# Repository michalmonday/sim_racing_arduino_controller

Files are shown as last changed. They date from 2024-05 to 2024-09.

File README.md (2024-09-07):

# sim_racing_arduino_controller

This sketch programs Arduino Pro Micro microcontroller to read Logitech pedals, Logitech shifter, and a handbrake as analog input pins. After programming, the microcontroller acts as a controller for sim racing games on PC (it works in all modern games like Assetto Corsa, ACC, iRacing, Forza Horizon 5, BeamNG, F1 23).

A nice feature of this setup is that a single USB connector provides the following inputs to a PC:
* pedals
* shifter
* handbrake
* potentially any other buttons (to add large number of buttons we could use a shift register)

You can see that on images, RS232 connectors have more wires than in the schematics, these are unused and can be ignored (they were connected during testing).

The latency of devices is around 35-40ms as measured during this test:  
https://www.youtube.com/watch?v=JN2piJnbTjY  
  
The sketch is using the ArduinoJoystickLibrary (tested with version 2.1.1):   
https://github.com/MHeironimus/ArduinoJoystickLibrary  

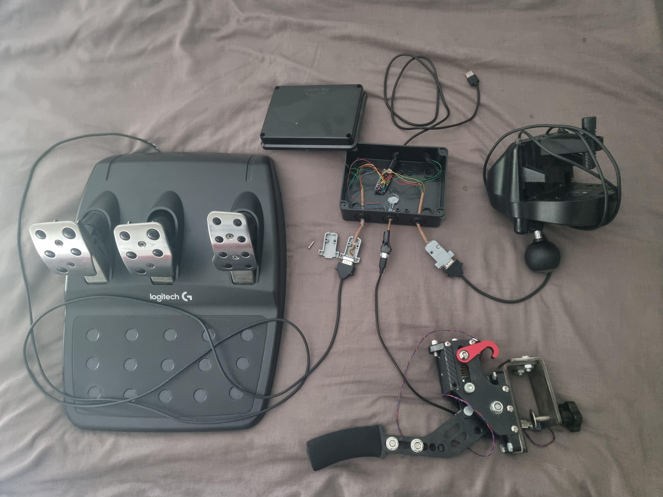
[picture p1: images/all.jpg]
ERROR: IMAGE NOT SHOWN

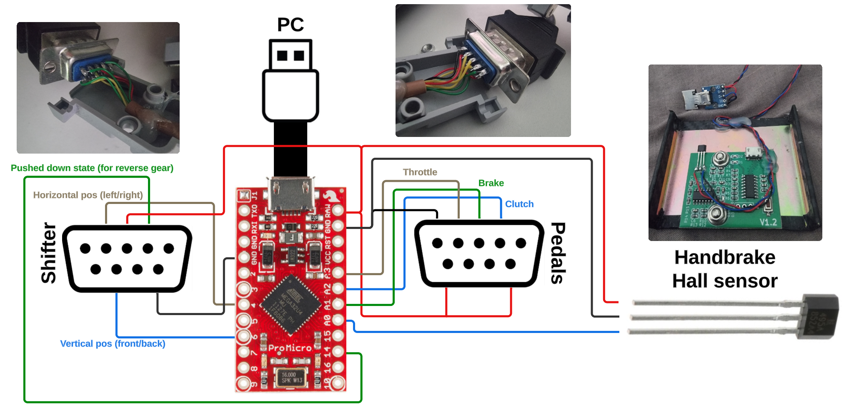
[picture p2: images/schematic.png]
ERROR: IMAGE NOT SHOWN


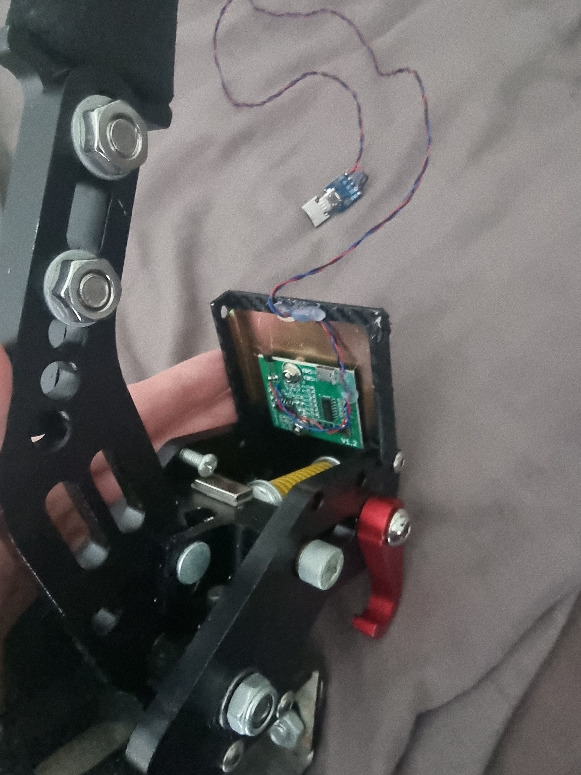
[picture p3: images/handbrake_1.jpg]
ERROR: IMAGE NOT SHOWN


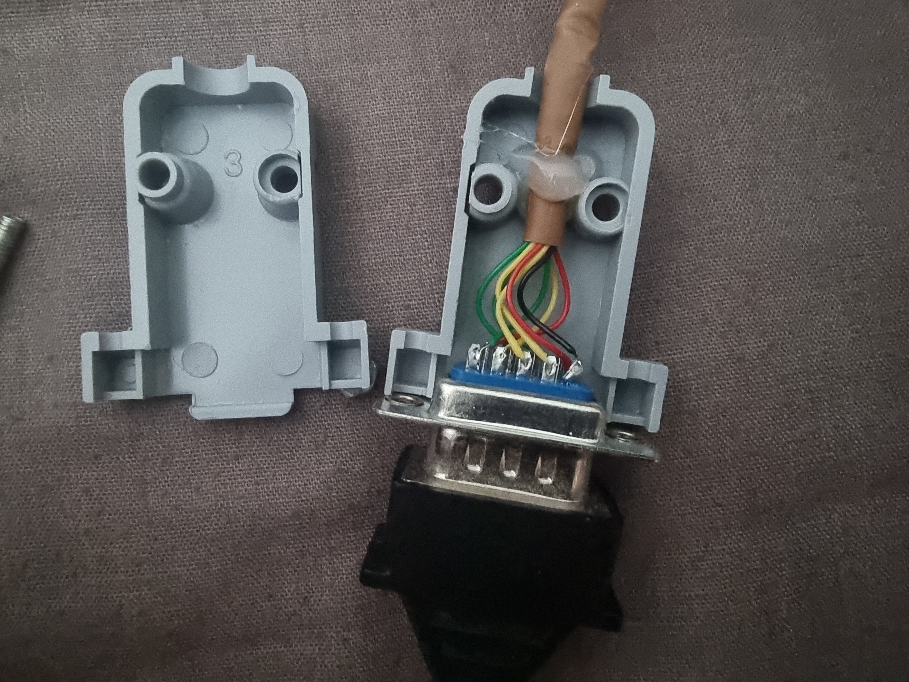
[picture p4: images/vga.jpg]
ERROR: IMAGE NOT SHOWN

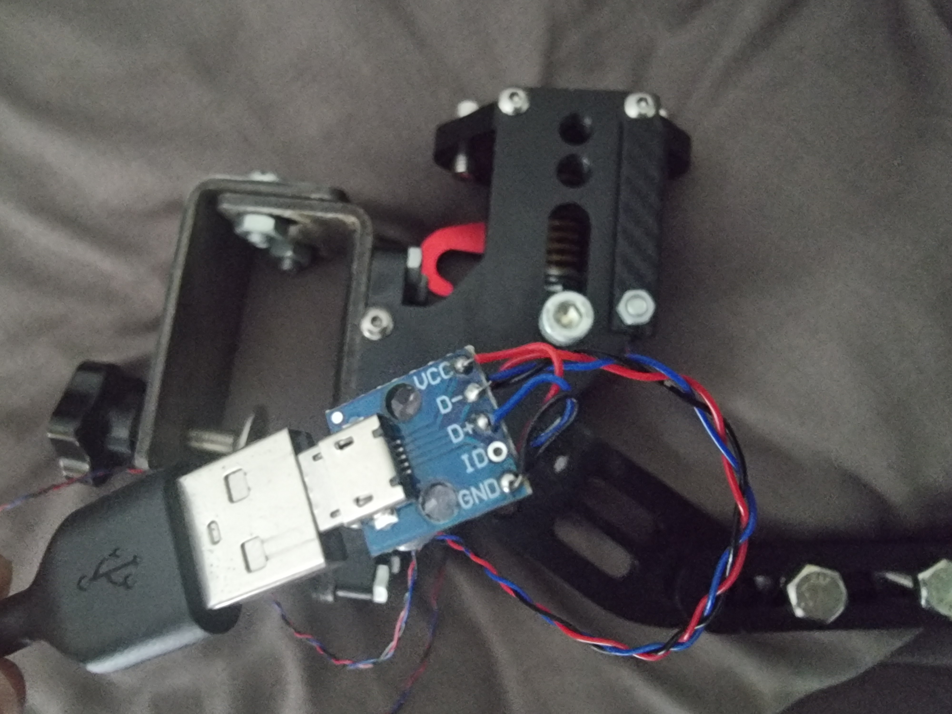
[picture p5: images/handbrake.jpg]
ERROR: IMAGE NOT SHOWN

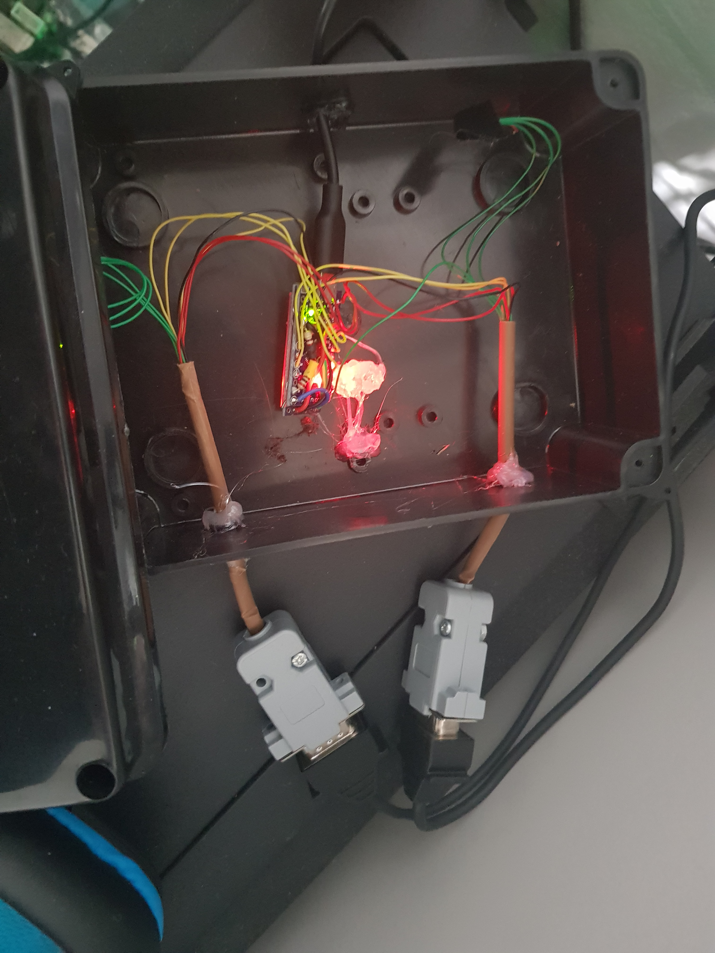
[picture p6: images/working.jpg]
ERROR: IMAGE NOT SHOWN


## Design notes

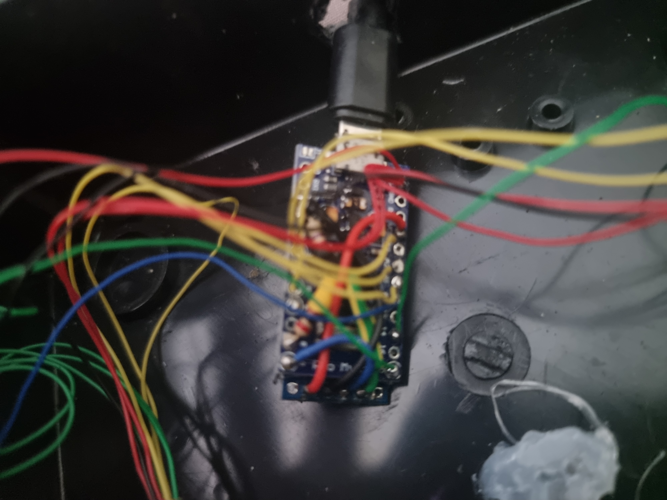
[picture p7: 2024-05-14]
images/close.jpg

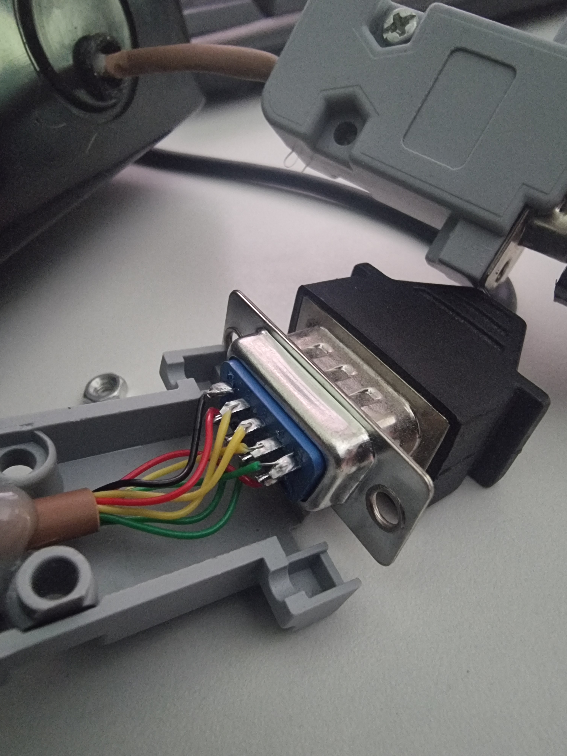
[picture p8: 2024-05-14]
images/rs232.jpg

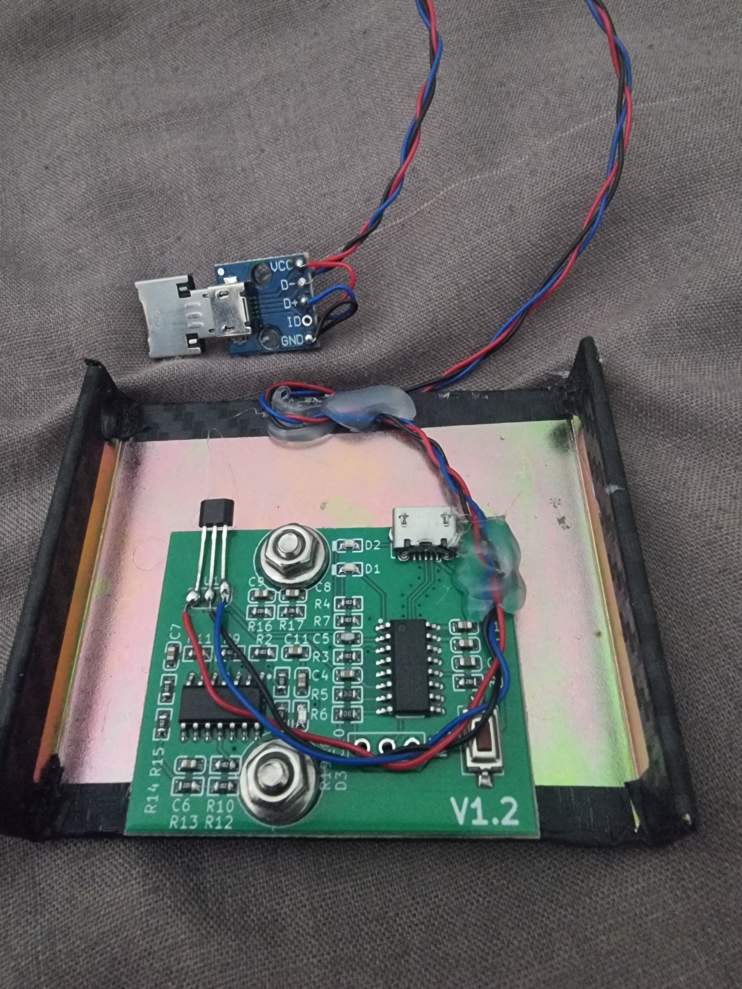
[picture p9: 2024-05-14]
images/handbrake_0.jpg

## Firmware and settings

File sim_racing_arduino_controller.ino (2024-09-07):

// This sketch programs Arduino Pro Micro microcontroller to read Logitech pedals,
// Logitech shifter, and a handbrake as analog input pins. After programming, the microcontroller  
// and acts as a controller for sim racing games on PC (works in all modern games like Assetto Corsa, 
// ACC, iRacing, Forza Horizon 5, BeamNG, F1 23).

// A nice feature of this setup is that a single USB connector provides the following inputs to a PC:
// - pedals
// - shifter
// - handbrake

// Another nice feature is that it could be easily extended with any Arduino sensors/buttons for custom controls.

#include <Joystick.h>



#include "Joystick.h"

#define PIN_SHIFTER_X A6
#define PIN_SHIFTER_Y A7
#define PIN_SHIFTER_REVERSE 14

#define PIN_PEDALS_CLUTCH A2
#define PIN_PEDALS_BRAKE A1
#define PIN_PEDALS_THROTTLE A3

#define PIN_HANDBRAKE A0
#define PIN_ANALOG_INPUT_UNUSED A10

#define BUTTON_COUNT 8


// MIN and MAX values constrain and scale analog read inputs of pedals. 
// (analog inputs should read values between 0 and 1023 but in reality that's not the case)
//
// The purpose of MIN value is to prevent detecting pedal press when it's physically released.
// When pedals are released the input values should be 0, but in reality are something like 50-90 (depending on pedal).
// Setting MIN values process is as follows:
// - open serial monitor
// - see analog read value of a pedal while it's fully released (press and release the pedal few times)
// - set MIN to the highest observed value (plus some added value for safety, if the highest observed value was 50, then MIN value should be 60-90, no less than 50 in any case)
// Setting MIN value too low will brake automatically without pressing the pedal.
// Setting MIN value too high will ignore pedal being pressed until it reaches certain point.

// Similarily, the purpose of MAX is to allow full range of input even if pressing a pedal does not result in 1023 value being registered.
// If we press the pedal fully, and the analog read returns less than 1023 (which is typically the case), the MAX value
// will scale the highest registered value (e.g. 990) to 1023.
// Setting MAX values process is as follows:
// - open serial monitor
// - see analog read value of a pedal while it's fully pressed
// - set MAX to the lowest observed value (minus some for safety, if the highest observed value was 990, then MAX value should be 940-970, no more than 990 in any case)
// Setting too high MAX value will prevent us from accellerating with 100% power. 
// Ssetting too low MAX value will set acceleration to 100% too early (e.g. when the pedal is pressed far from its full range).
#define CLUTCH_MIN 120
#define CLUTCH_MAX 940

#define BRAKE_MIN 80
#define BRAKE_MAX 880

#define THROTTLE_MIN 110
#define THROTTLE_MAX 950

#define HANDBRAKE_MIN 560
#define HANDBRAKE_MAX 730


Joystick_ pedals(
  0x03,                       // Default, don't change
  JOYSTICK_TYPE_MULTI_AXIS,   // Type
  BUTTON_COUNT,               // Button Count
  0,                          // HatSwitch Count
  false,                      // includeXAxis
  false,                      // includeYAxis
  false,                      // includeZAxis
  false,                      // includeRxAxis
  false,                      // includeRyxis
  false,                      // includeRzxis
  false,                       // includeRudder
  true,                       // includeThrottle
  true,                       // includeAccelerator
  true,                       // includeBrake
  true                      // includeSteering
  
);

/*
//Joystick_(0x03, JOYSTICK_TYPE_GAMEPAD, 4, 2, true, true, false, false, false, false, false, false, false, false, false),
Joystick_ gamepad(
  0x04,                       // Default, don't change
  JOYSTICK_TYPE_GAMEPAD,      // Type
  0,                          // Button Count
  2,                          // HatSwitch Count
  false,                       // includeXAxis
  false,                       // includeYAxis
  false,                       // includeZAxis
  true,                      // includeRxAxis
  true,                      // includeRyxis
  false,                      // includeRzxis
  false,                      // includeRudder
  false,                      // includeThrottle
  false,                      // includeAccelerator
  false,                      // includeBrake
  false                       // includeSteering
);*/

#define BTN_GEAR_NEUTRAL 0
#define BTN_GEAR_1 1
#define BTN_GEAR_2 2
#define BTN_GEAR_3 3
#define BTN_GEAR_4 4
#define BTN_GEAR_5 5
#define BTN_GEAR_6 6
#define BTN_GEAR_REVERSE 7

constexpr long int RANGE_LIMIT{ 1023 };

int last_gear = -1;

void reset_shifter_buttons() {
  for (int i=0; i < BUTTON_COUNT; i++) {
     pedals.setButton(i, LOW);
  }
}

int shifter_pos_to_btn_gear(int x, int y) {
  if (x < 436) {
    if (y < 363) return BTN_GEAR_2;
    if (y > 733) return BTN_GEAR_1;
    return BTN_GEAR_NEUTRAL;
  } 

  // x right
  if (x > 621) {
    if (y < 363) return BTN_GEAR_6;
    if (y > 733) return BTN_GEAR_5;
    return BTN_GEAR_NEUTRAL;
  }

  // x middle
  if (y < 363) return BTN_GEAR_4;
  if (y > 733) return BTN_GEAR_3;
  return BTN_GEAR_NEUTRAL;
}


void setup() {
    Serial.begin(9600);
    pedals.setThrottleRange(0, RANGE_LIMIT);
    pedals.setRudderRange(0, RANGE_LIMIT);
    pedals.setAcceleratorRange(0, RANGE_LIMIT);
    pedals.setBrakeRange(0, RANGE_LIMIT);
    pedals.setSteeringRange(0, RANGE_LIMIT);
    
    pedals.begin();

    //gamepad.begin();

    pinMode(PIN_SHIFTER_REVERSE, INPUT);
    pinMode(PIN_SHIFTER_X, INPUT_PULLUP); 
    pinMode(PIN_SHIFTER_Y, INPUT_PULLUP); 

    pinMode(PIN_HANDBRAKE, INPUT_PULLUP);
}

void loop() {
    
    int rawClutchPosition = constrain( analogRead(PIN_PEDALS_CLUTCH), CLUTCH_MIN, CLUTCH_MAX); 
    
//    Serial.print("Clutch - ");
//    Serial.print(rawClutchPosition, DEC);
    int mappedClutchPosition = map(rawClutchPosition, CLUTCH_MIN, CLUTCH_MAX, RANGE_LIMIT, 0);
    pedals.setAccelerator(mappedClutchPosition);
//    Serial.print(" ("+String(mappedClutchPosition)+") ");


    int rawAcceleratorPosition = constrain( analogRead(PIN_PEDALS_THROTTLE), THROTTLE_MIN, THROTTLE_MAX );
//    Serial.print(" | Accelerator - ");
//    Serial.print(rawAcceleratorPosition, DEC);
    int mappedAcceleratorPostion = map(rawAcceleratorPosition, THROTTLE_MIN, THROTTLE_MAX, RANGE_LIMIT, 0);
    pedals.setThrottle(mappedAcceleratorPostion);
//    Serial.print(" ("+String(mappedAcceleratorPostion)+") ");

    int rawBrakePosition = constrain( analogRead(PIN_PEDALS_BRAKE), BRAKE_MIN, BRAKE_MAX );
//    Serial.print(" | Brake - ");
//    Serial.print(rawBrakePosition, DEC);
    int mappedBrakePosition = map(rawBrakePosition, BRAKE_MIN, BRAKE_MAX, RANGE_LIMIT, 0);
    pedals.setBrake(mappedBrakePosition);
//    Serial.print(" ("+String(mappedBrakePosition)+") ");

    int gear = shifter_pos_to_btn_gear(analogRead(PIN_SHIFTER_X), analogRead(PIN_SHIFTER_Y));
    if (gear == BTN_GEAR_6 && digitalRead(PIN_SHIFTER_REVERSE)) {
      gear = BTN_GEAR_REVERSE;
    }

//    Serial.print(" | Shifter - ");
//    Serial.print(analogRead(PIN_SHIFTER_X), DEC);
//    Serial.print(" x ");
//    Serial.print(analogRead(PIN_SHIFTER_Y), DEC);
    

//    if (gear == BTN_GEAR_REVERSE) {
//      Serial.print("(gear reverse)");
//    } else {
//      Serial.print("(gear " + String(gear) + ")");
//    }

    int rawHandbrake = constrain(analogRead(PIN_HANDBRAKE), HANDBRAKE_MIN, HANDBRAKE_MAX);
    int mappedHandbrakePosition = map(rawHandbrake, HANDBRAKE_MAX, HANDBRAKE_MIN, RANGE_LIMIT, 0);
    pedals.setSteering(mappedHandbrakePosition);
//    Serial.print(" | Handbrake - " + String(rawHandbrake) + " (" + String(mappedHandbrakePosition) + ")");
//    
//    Serial.println(" ");


    if (last_gear != gear) {
      reset_shifter_buttons();
      pedals.setButton(gear, HIGH);
      Serial.println("GEAR CHANGED FROM " + String(last_gear) + " TO " + String(gear));
      last_gear = gear;
    }
    
    //delay(20);
}

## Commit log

2024-05-14 Schematic and images
    [fritzing_project.fzz]
2024-09-07 updated readme + got rid of 'delay' and Serial.print messages
